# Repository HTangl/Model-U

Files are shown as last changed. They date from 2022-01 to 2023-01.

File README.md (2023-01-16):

# Model UD

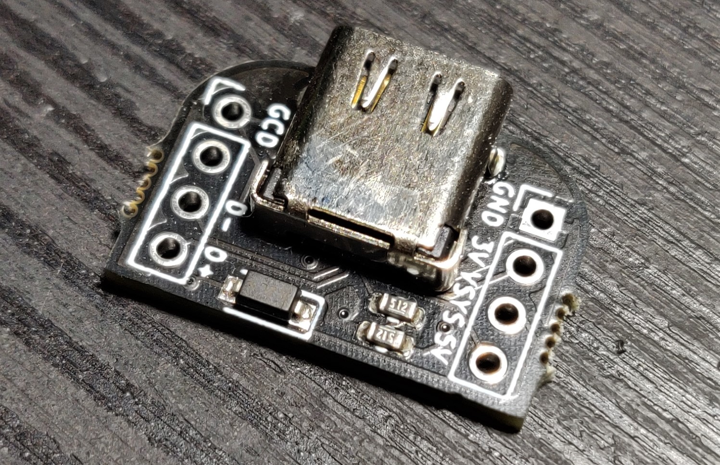
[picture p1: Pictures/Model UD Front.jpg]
  

The Model UD is a USB C breakout board based on the Model U designed by [Crane](https://github.com/Crane1195). It is exactly the same size and footprint as the Model U but integrates a schottky diode directly onto the board and adds the "VSYS" pin. This eliminates the need to add a stand alone diode to your circuit when wiring to a Raspberry Pi Pico. You can simply run a wire directly from the VSYS pin on the model UD to the VSYS pin on the Pico.  

The Model UD is specifically designed for use with DIY rectangle controllers to facilitate the use of USB C to GC cables as well as standard USB C to USB A cables.  

I sell these on my [Etsy shop](https://www.etsy.com/shop/HTangl).  

Here is a wiring guide.  
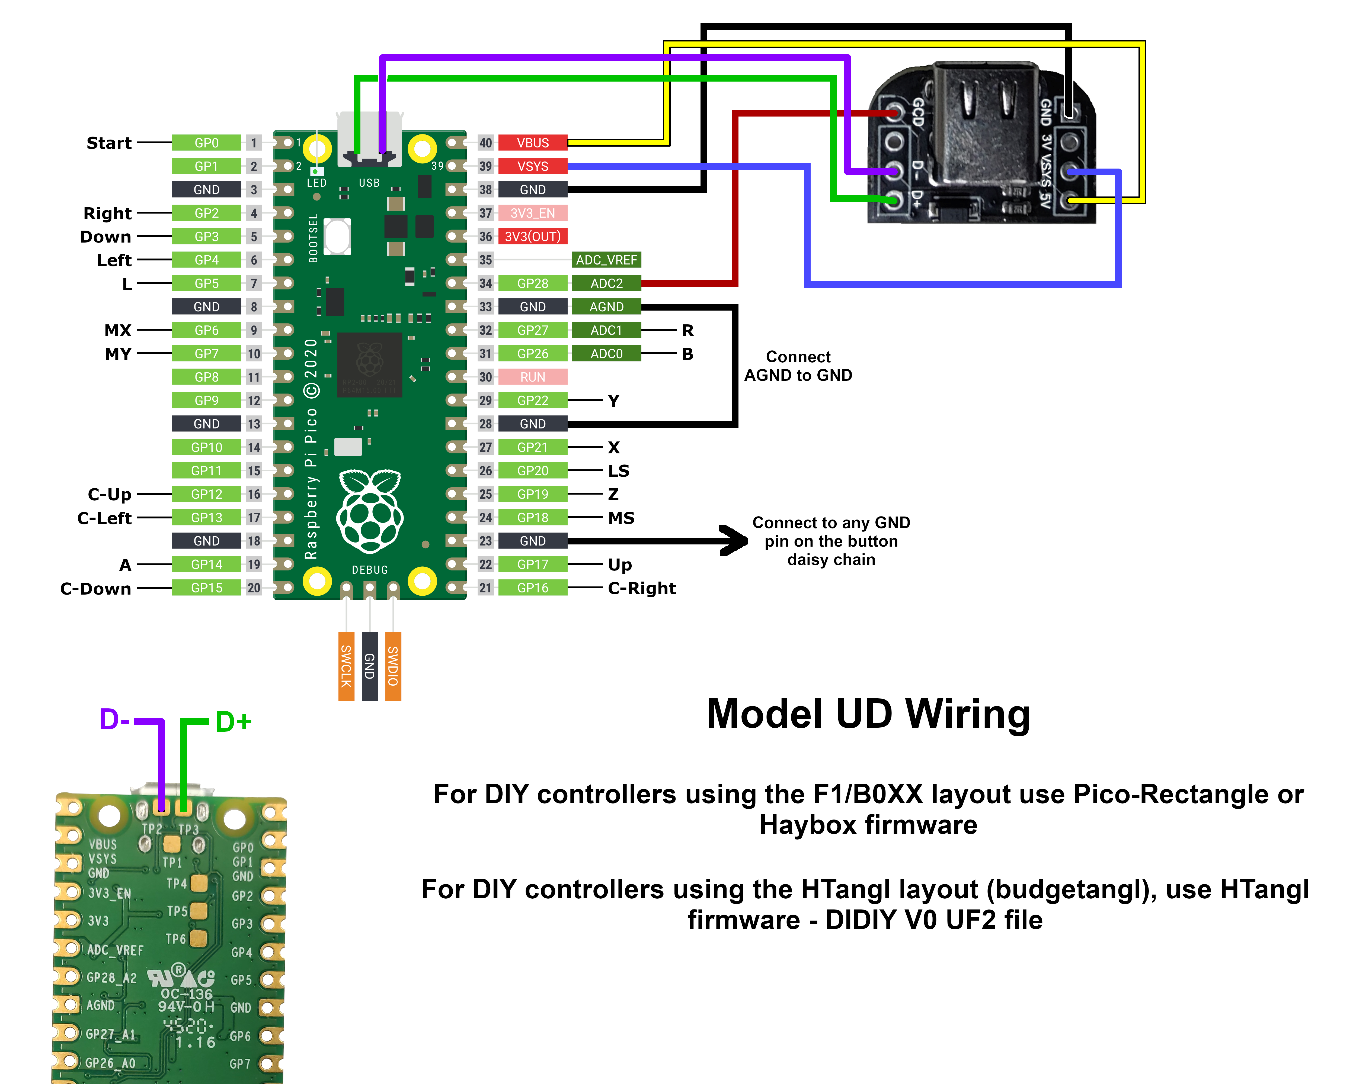
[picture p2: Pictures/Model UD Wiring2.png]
  

This repository contains the files necessary to order these boards from [JLCPCB](https://jlcpcb.com/).  
Please be aware that JLC does not have a great track record when it comes to SMT part assembly.  
It is normal to receive 1 to 4 bad boards in every batch.  
There is a guide at the bottom of this page that explains how to test the boards.  

There are also files for a modified version of the board with 3mm mounting holes added if you plan to mount the board with screws. These are the "Model BirdD" files, cuz they kinda look like a Model UD with wings.  
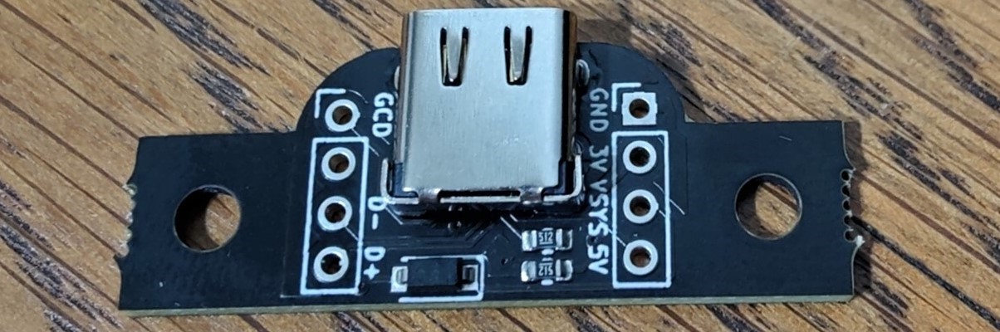
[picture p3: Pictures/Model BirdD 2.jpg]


### How to order from JLCPCB ###

1. Download the files from this repository by clicking on "Code" and then on "Download Zip". Unzip the "Model-UD-main.zip" but do not unzip the "Model-UD_panel.zip" folders  
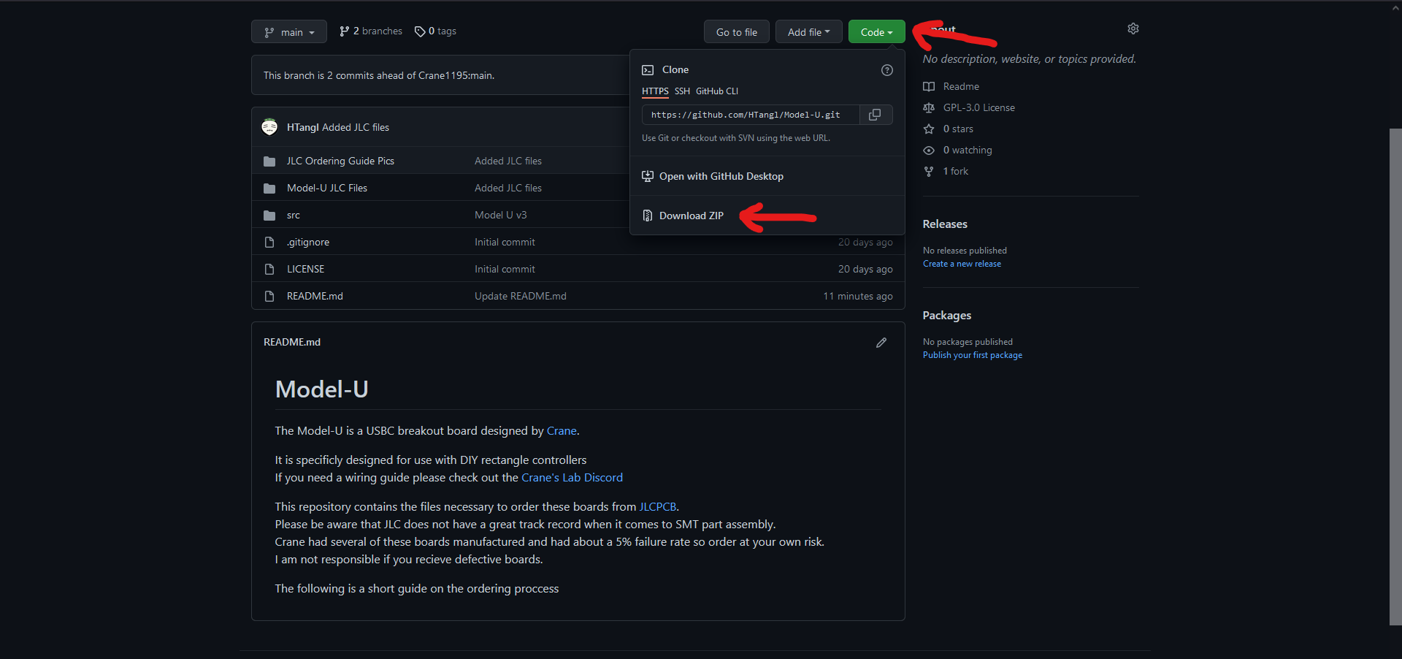
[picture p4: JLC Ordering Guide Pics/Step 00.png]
  

2. From the JLCPCB home page click on "Order now"  
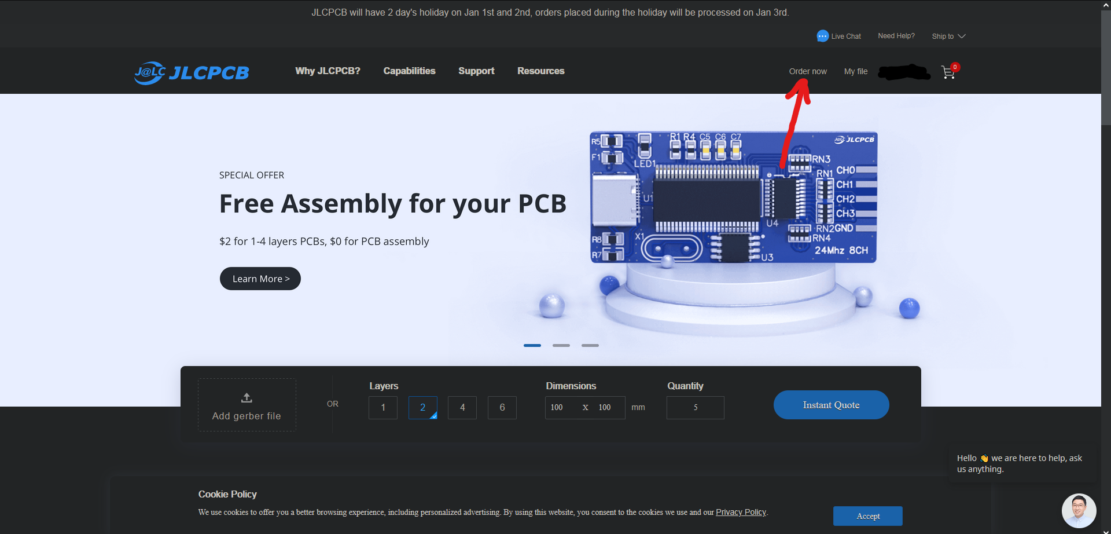
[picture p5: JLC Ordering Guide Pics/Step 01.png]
  

3. On the next page click the "Add gerber file" button and select one of the "Model-UD_panel.zip" files in the "Model-UD JLC Files" folder. For this guide I'm using the 10 piece panel. Keep in mind JLC's minimum order quantity is 5 so since I'm using the 10 piece panel file I will end up with 50 individual breakout boards total.  
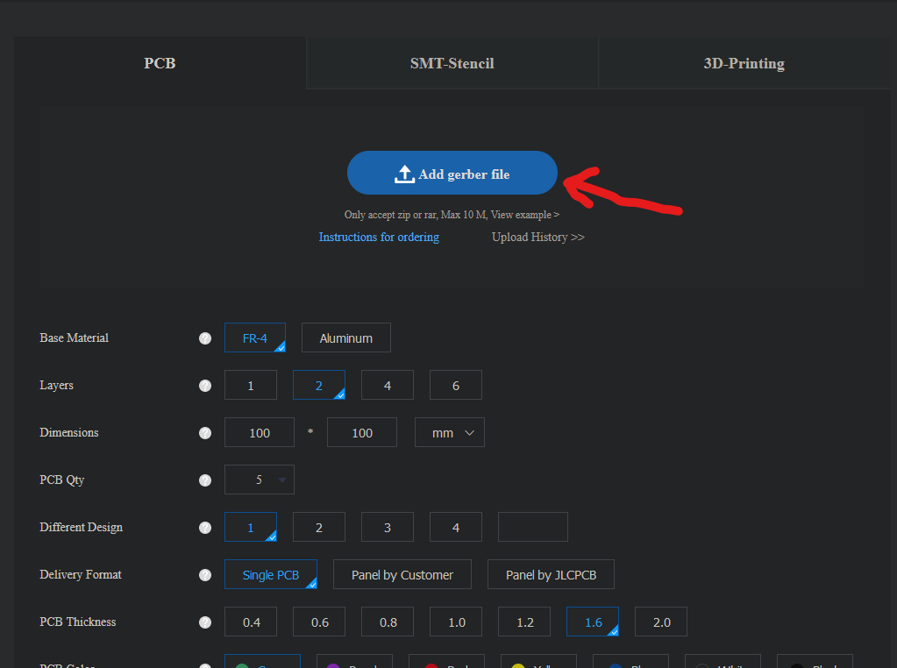
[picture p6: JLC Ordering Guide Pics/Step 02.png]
  

4. Change the delivery format to "Panel by Customer" and then input the amount of rows and columns needed, for the 10 piece panel it is 2 columns and 5 rows  
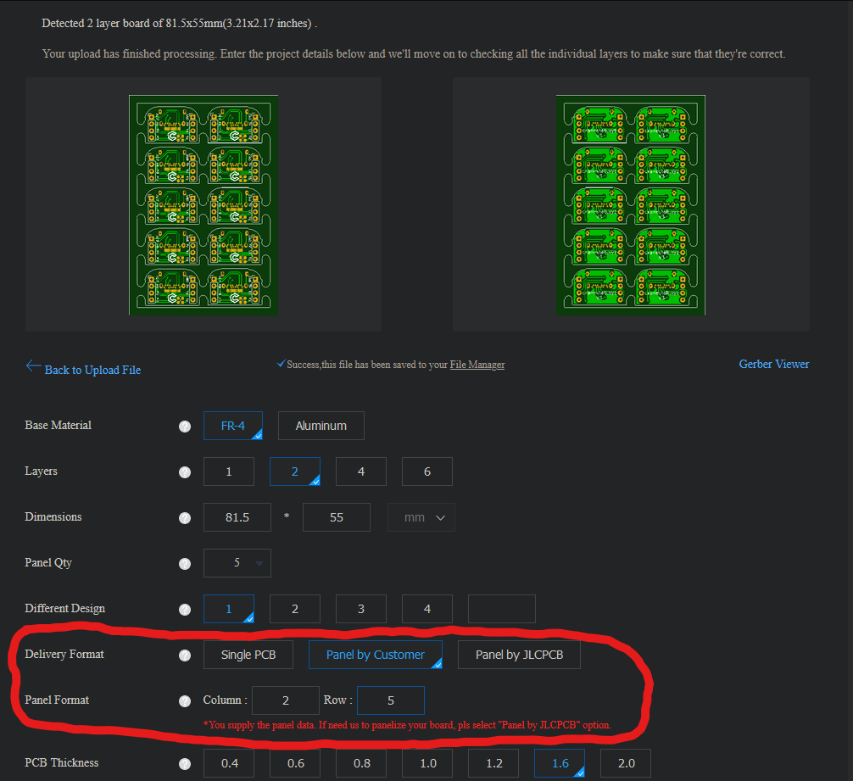
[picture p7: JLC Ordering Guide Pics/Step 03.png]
  

5. Scroll down and turn on the "SMT Assembly" slider, leave everything default and then click "Confirm"  
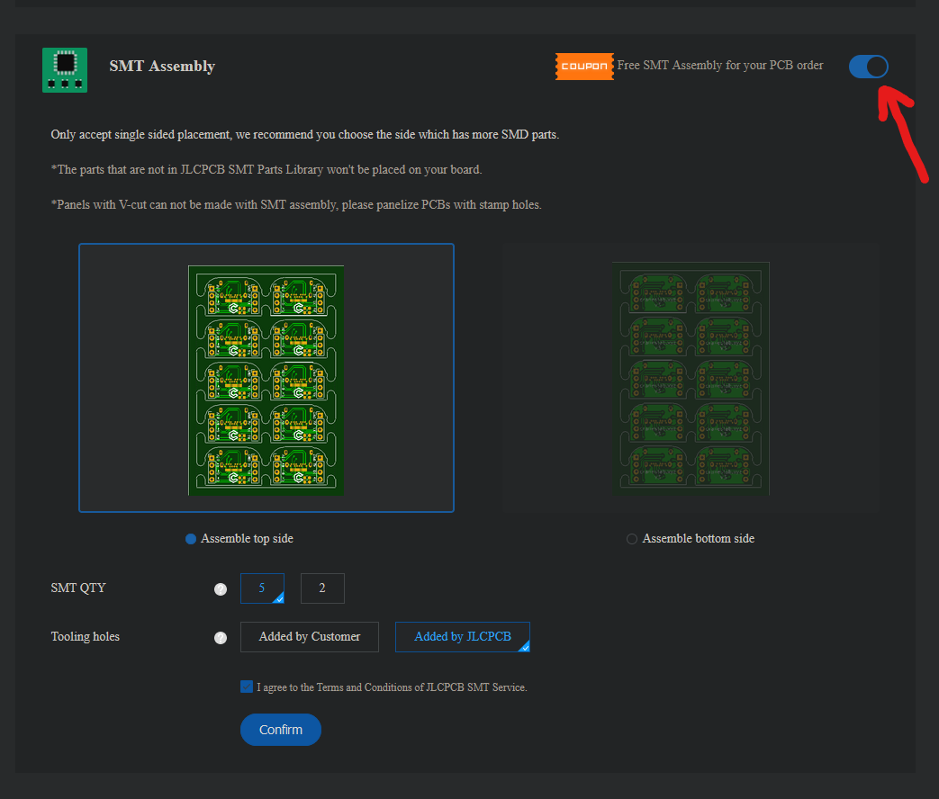
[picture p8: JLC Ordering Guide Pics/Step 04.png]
  

6. On the next page add the BOM and CPL files from the "Model-UD JLC Files" folder. Then select the "Single Piece" button and then click "NEXT"  
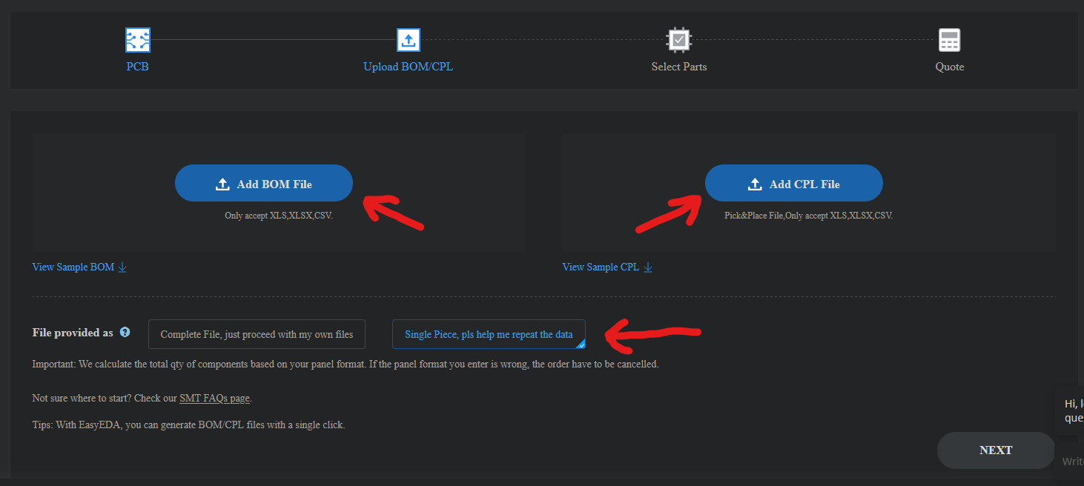
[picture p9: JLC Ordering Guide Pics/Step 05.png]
  

7. On this page just leave everything default and click "NEXT"  
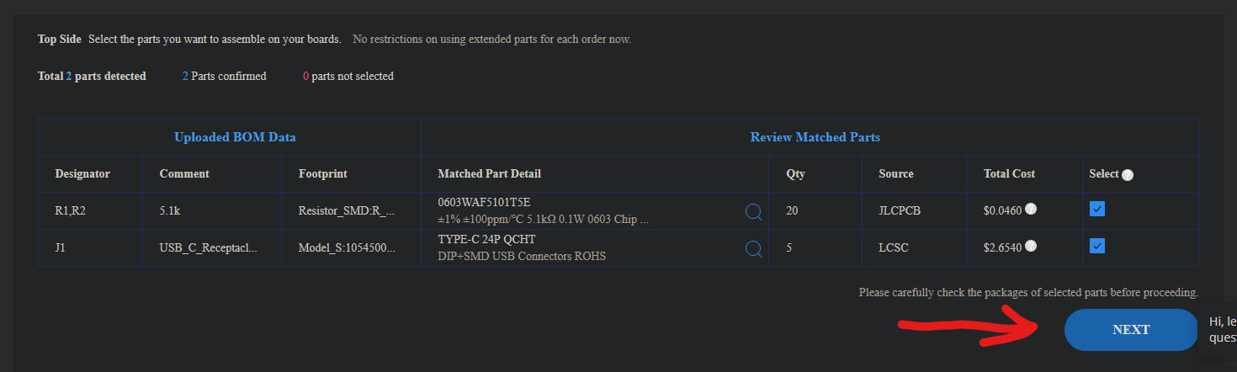
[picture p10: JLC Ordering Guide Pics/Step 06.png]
  

8. The final step will show you a preview of what the boards will look like. It is normal for the parts to be off center and only displayed on one board. JLC will place the parts correctly after you place the order. Also note that if you are ordering less than 50 individual breakout boards you will still be charged for 100 resistors, this is normal and is just a JLC policy. For some small parts they have a minimum quantity. Lastly please do not use the price listed in this picture as a reference, the price shown doesn't include tax or shipping and JLC does change their price from time to time. All you have to do now is click "SAVE TO CART" and then finish the checkout process  
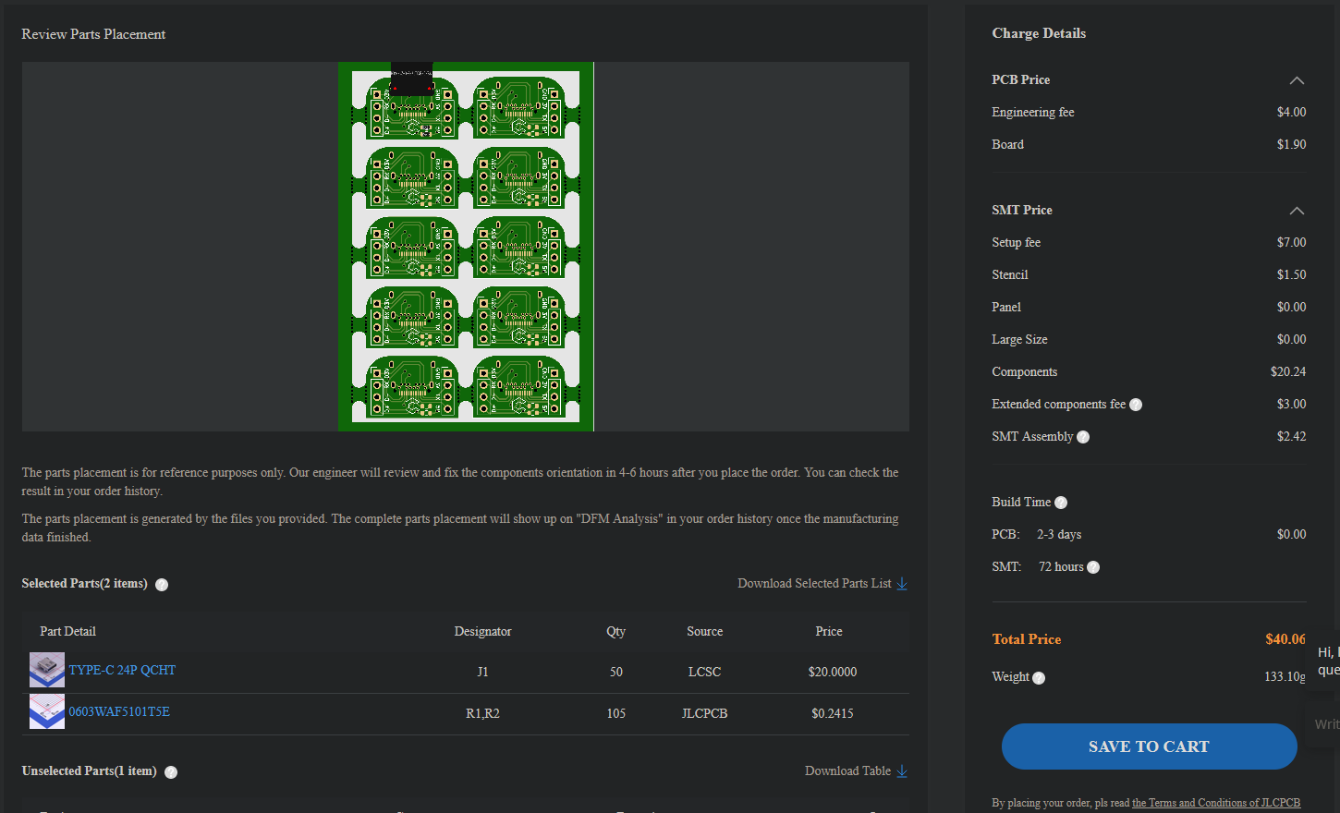
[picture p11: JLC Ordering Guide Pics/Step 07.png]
  

### Testing the boards ###

If you plan to sell these I recommend testing them first.  
To do this you will need a USB C to USB C 3.1 gen 2 cable and a 24 pin USB C breakout board.  
Here are links to the breakout board and cable that I use.  
Breakout: https://amazon.com/dp/B07771CFFM or https://amazon.com/dp/B09L816S5W  
USB Cable: https://amazon.com/dp/B07THFJ1J5  

To test the boards you need a multi-meter with a continuity testing mode.  
Start by connecting the Model UD to the 24 pin breakout.  
Next put one lead of the meter on any pin of the Model UD and then drag the other lead of your meter across every pin on the 24 pin breakout.  
Use the chart below to determine which pins should have continuity.  
If you get continuity on a pin that should not have continuity, such as D+ on the Model UD getting continuity on a GND pin, then the Model UD is broken.  

The pins on the left are the Model UD and the right is the 24 pin breakout.  
Please note that if you'd like to test the diode connected to the VSYS pin you will need a meter with a diode test mode and test between the VSYS and 3V pins, this is generally not needed as the chance of having a bad diode is extremely low.  

5V - VBUS (A4, A9, B4, B9)  
3V - RX1/2+ (A11, B11)  
Gnd - GND and Shield (if applicable) (A1, A12, B1, B12)  
D+ - D+ (Either A6 or B6 you will only get continuity on one)  
D3V - TX1/2+ (A2, B2)

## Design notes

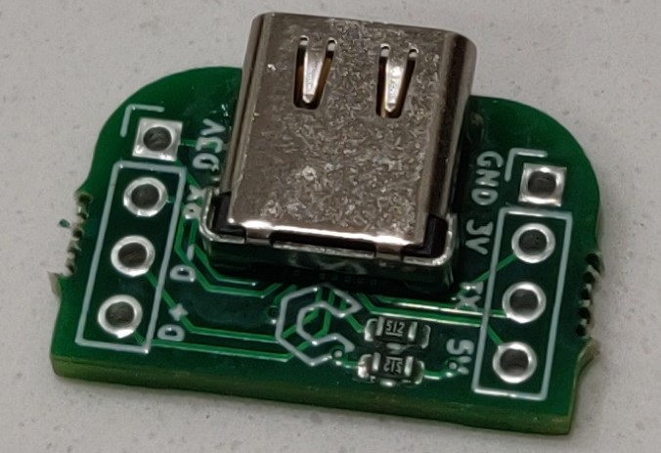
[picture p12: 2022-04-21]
Pictures/Model-U.jpg

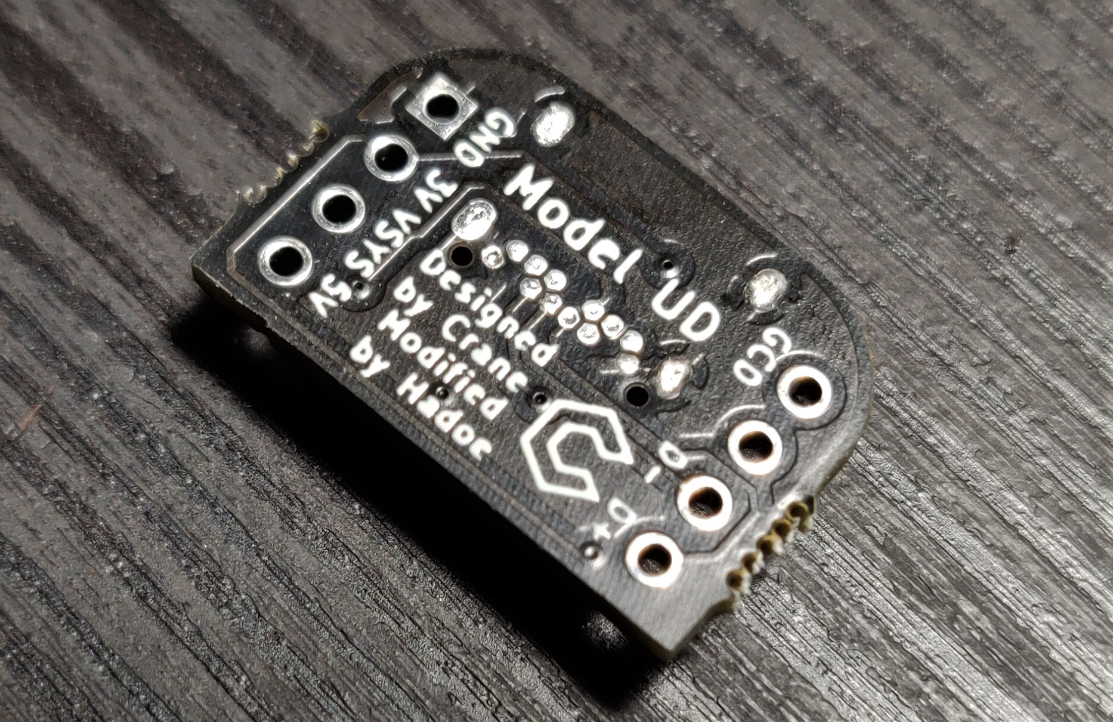
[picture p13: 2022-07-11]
Pictures/Model UD Back.jpg

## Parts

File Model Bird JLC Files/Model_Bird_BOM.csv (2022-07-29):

Comment | Designator | Footprint | LCSC
USB_C_Receptacle | J1 | Model_S:1054500101 | C456013
5.1k | R1,R2 | Resistor_SMD:R_0603_1608Metric | C23186

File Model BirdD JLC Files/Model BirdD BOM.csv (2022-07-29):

Comment | Designator | Footprint | LCSC
USB_C_Receptacle | J1 | Model_S:1054500101 | C456013
B5819W | D1 | Diode_SMD:D_SOD-123 | C8598
5.1k | R1,R2 | Resistor_SMD:R_0603_1608Metric | C23186

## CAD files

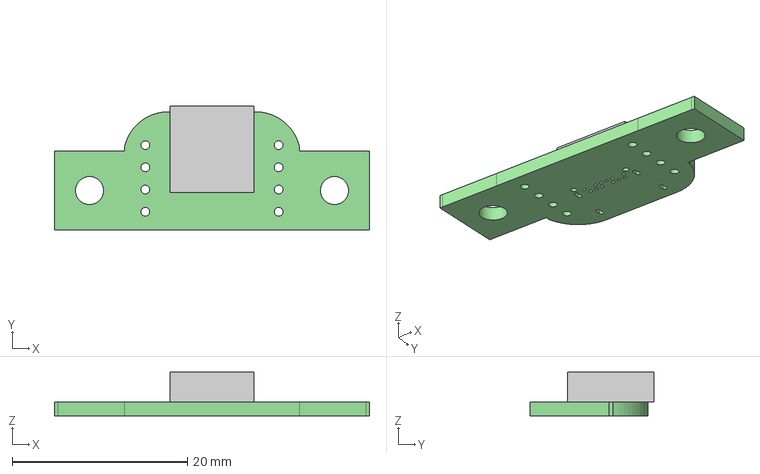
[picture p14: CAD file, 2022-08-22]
3D Models/Model BirdD.step
36.0 x 14.2 x 5.00 mm
Model Bird PCB

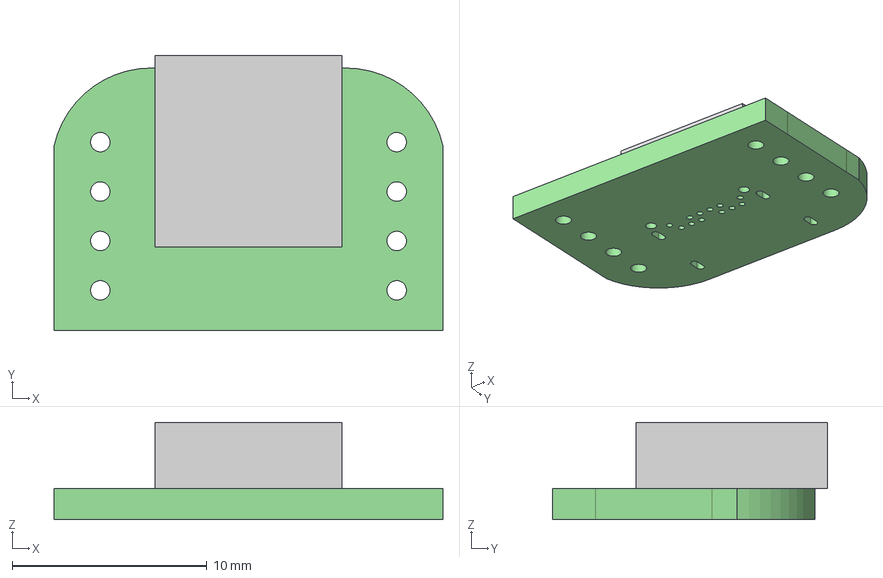
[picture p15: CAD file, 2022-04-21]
3D Models/Model-U.step
20.0 x 14.2 x 5.00 mm

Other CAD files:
3D Models/Model BirdD.f3d
3D Models/Model-U.f3d

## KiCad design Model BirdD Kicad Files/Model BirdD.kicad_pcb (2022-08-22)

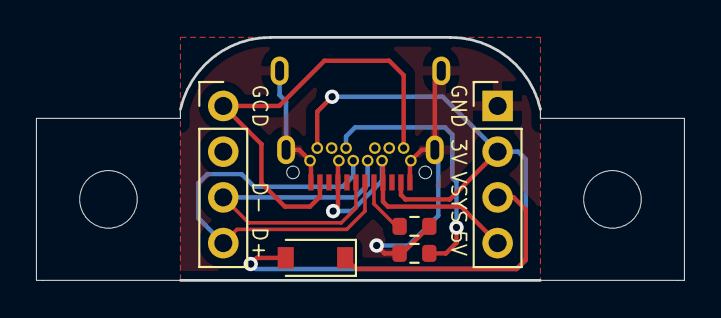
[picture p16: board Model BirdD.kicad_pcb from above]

Board: 2 copper layers, 36.0 x 13.5 mm, 6 parts (0 on the bottom side), 9 nets.

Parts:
D1: MBR120; D_SOD-123
J1: USB_C_Receptacle; Shou Han Type-C 24P QCHT
J2, J3: Conn_01x04; PinHeader_1x04_P2.54mm_Vertical
R1: 5.1k; R_0603_1608Metric
RE: 5.1k; R_0603_1608Metric

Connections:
3V3: D1.2 (A), J1.A2, J1.B2, J3.2
D3V: J1.A11, J1.B11, J2.1
D+: J1.A6, J1.B6, J2.4
D-: J1.A7, J1.B7, J2.3
GND: J1.A1, J1.A12, J1.B1, J1.B12, J1.S1, J3.1, R1.1, RE.2
unnamed: J1.A5, R1.2
unnamed: J1.B5, RE.1
VBUS: J1.A4, J1.A9, J1.B4, J1.B9, J3.4
VSYS: D1.1 (K), J3.3

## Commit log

2022-01-14 Added gerber files for single PCB
2022-04-21 Add Model Bird Files
    Added model bird files along with more pictures and 3D model files
    [Model Bird.f3d, Model Bird.kicad_pcb, Model Bird.sch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]
2022-07-11 Change files to Model UD
    [Model UD Panel 10.kicad_pcb, Model UD Panel 4.kicad_pcb, Model UD.kicad_pcb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]
2022-07-11 Add wiring picture
2022-07-29 Add missing BOM and CPL files
    [Model UD BOM.csv, Model_Bird_BOM.csv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]
2022-08-22 Add Model BirdD files
    [Model Bird.f3d, Model Bird.kicad_pcb, Model Bird.sch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]
2022-08-23 Rename Gerber file
2022-12-19 change wiring and board pictures
2023-01-16 Create Model UD Wiring2.png
2023-01-16 Update wiring picture
